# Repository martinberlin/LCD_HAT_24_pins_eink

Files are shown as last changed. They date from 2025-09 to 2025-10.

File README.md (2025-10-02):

LCD_HAT with 24 pin SPI Eink circuit<br>
-----------------------------------

Copyright (c) 2023 BitBank Software, Inc.<br>
bitbank@pobox.com<br>
<br>
Collaboration to make the SPI Eink port by [Fasani Corp](https://fasani.de)

A simple PCB to easily connect LCD breakout boards to Arduino Nano or Feather MCU boards. Includes 2 momentary push buttons and Qwiic I2C connector. The GPIOs used for the LCD connection are marked next to the female header. Likewise the buttons.
<br>
This photo shows an Arduino Nano RP2040 Connect and UnexpectedMaker FeatherS3 both using the same board and 2 types of LCDs supported with this pinout:
<br>
<br>
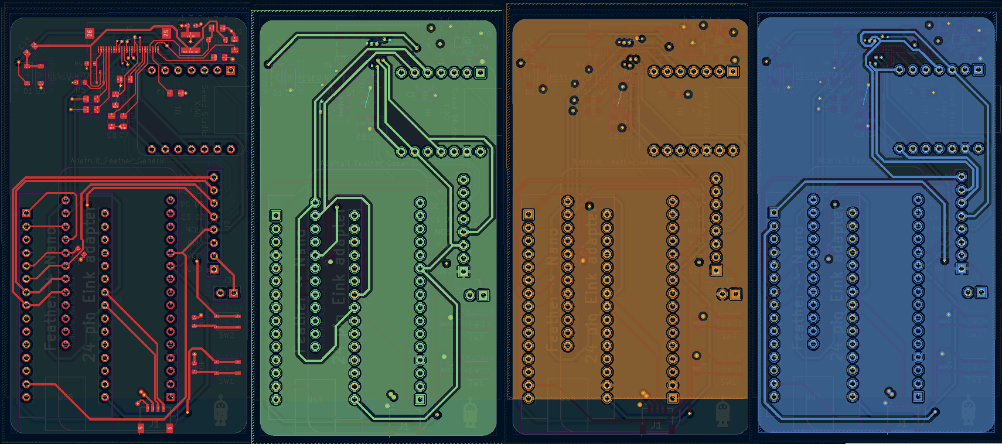
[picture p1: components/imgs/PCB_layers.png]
LCD_HAT layers

<br>
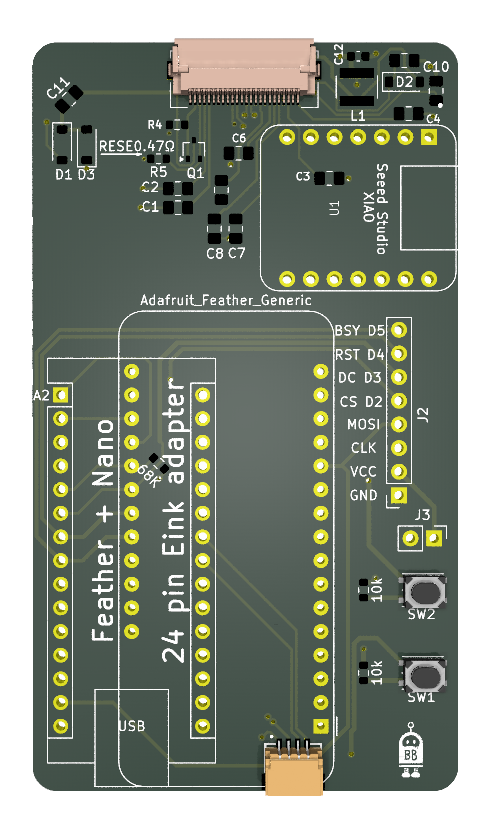
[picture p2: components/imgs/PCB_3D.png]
LCD_HAT 3D Render LCD_HAT 3D


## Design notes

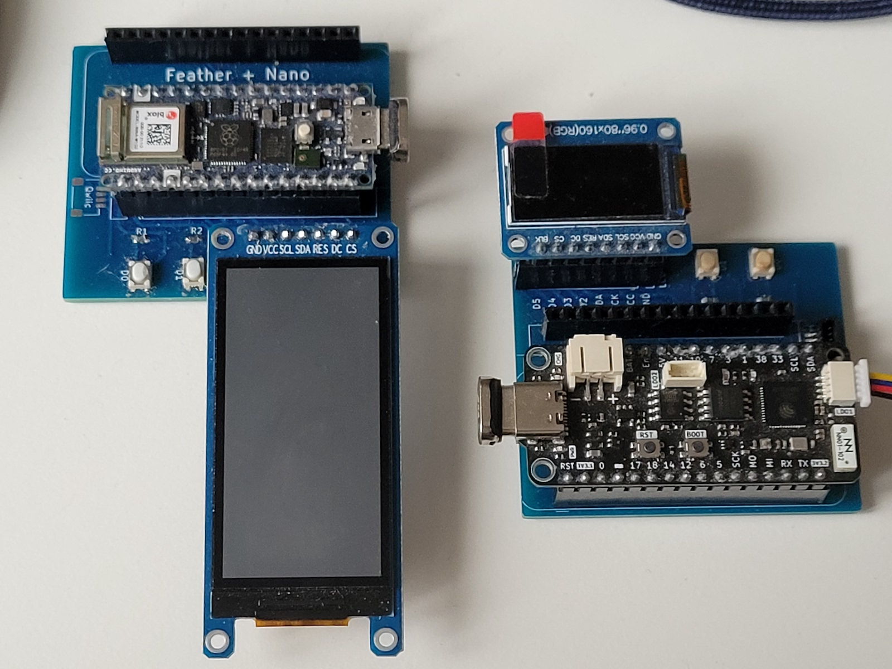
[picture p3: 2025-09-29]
demo.jpg

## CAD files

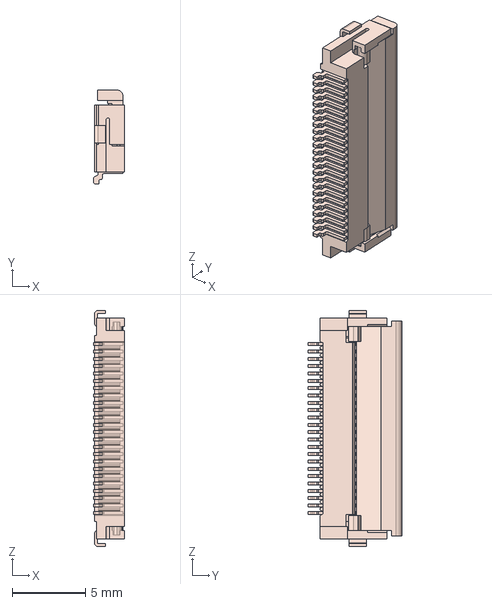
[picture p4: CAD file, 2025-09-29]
components/3d/FH12-24S-0.5SH_55_.step
2.10 x 6.40 x 16.1 mm

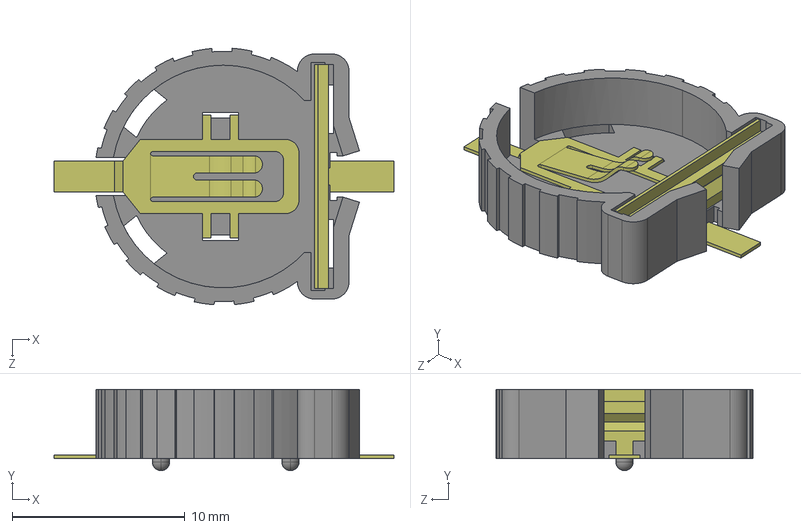
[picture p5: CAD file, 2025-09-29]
components/3d/CR1220-2.step
19.7 x 4.70 x 14.9 mm

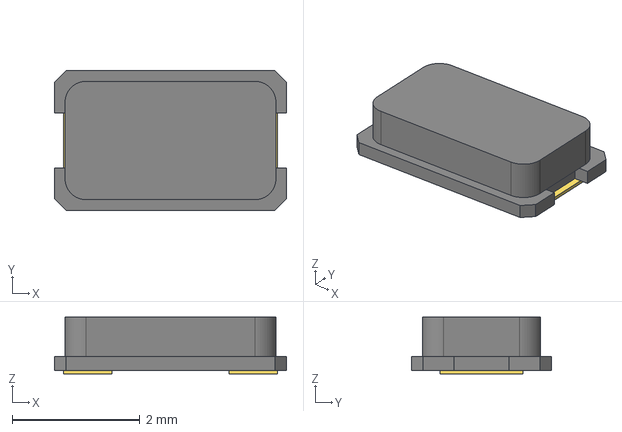
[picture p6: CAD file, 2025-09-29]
components/3d/XTAL_FC-135_EPS.step
3.63 x 2.18 x 0.889 mm

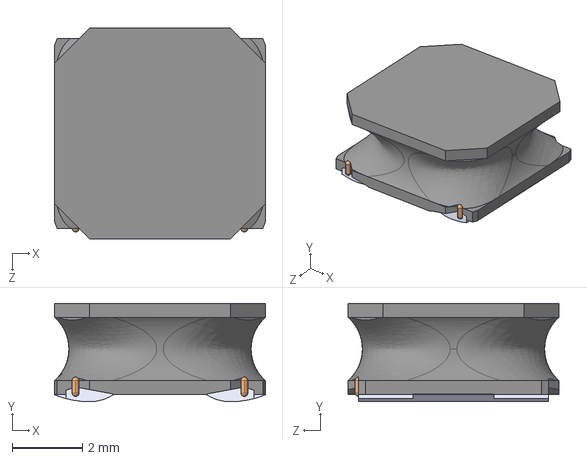
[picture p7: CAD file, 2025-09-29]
components/3d/L-40xx.STEP
6.00 x 2.80 x 6.00 mm

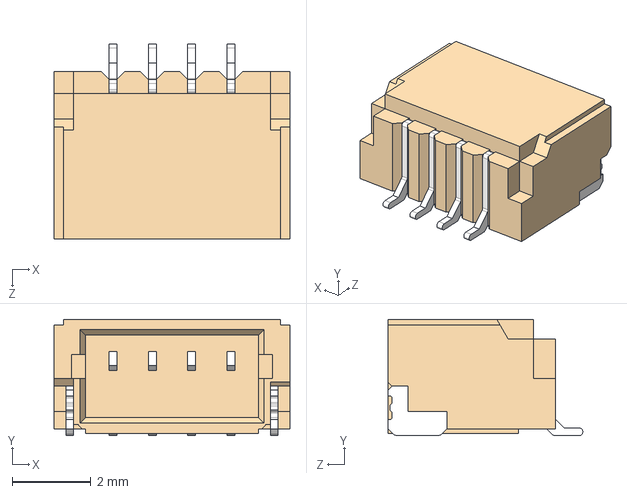
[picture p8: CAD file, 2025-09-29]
components/3d/QWIIC_SM04B-SRSS-TB_LF__SN_.stp
6.00 x 2.96 x 4.95 mm

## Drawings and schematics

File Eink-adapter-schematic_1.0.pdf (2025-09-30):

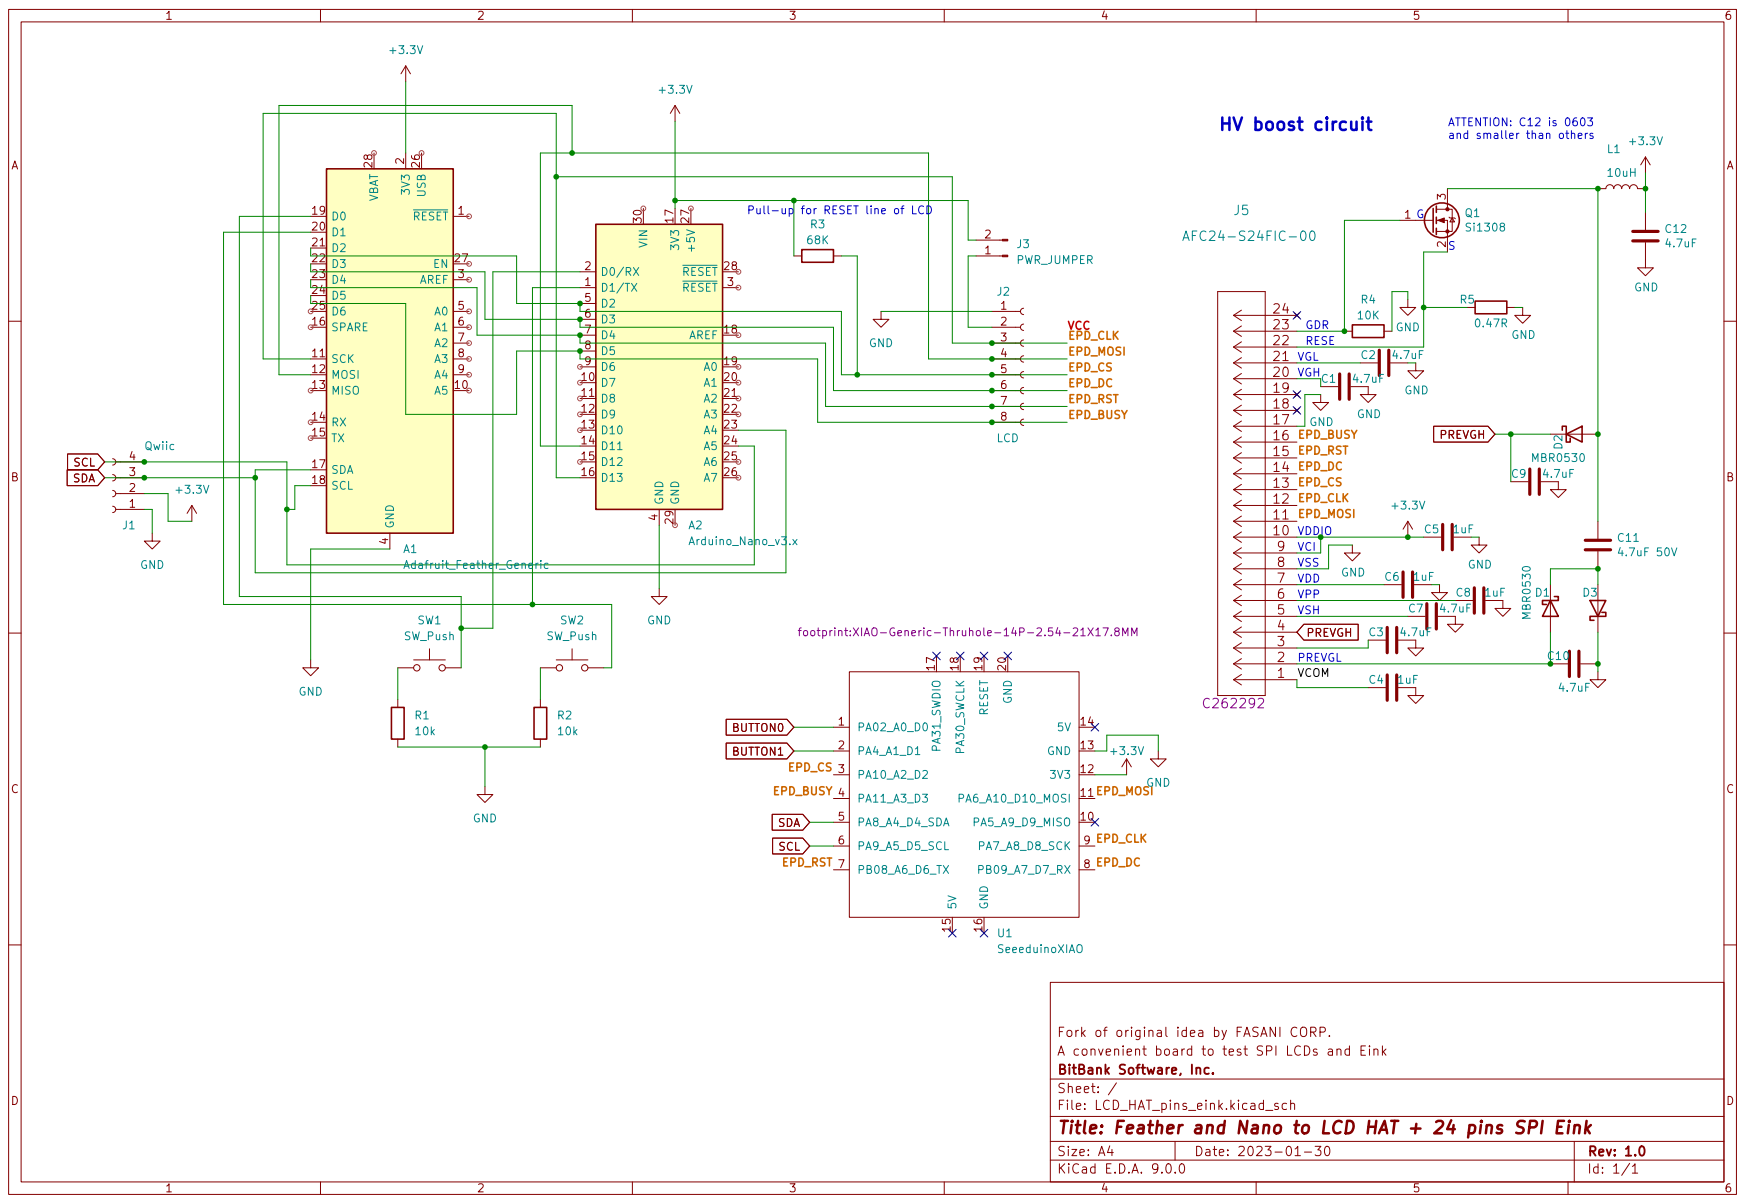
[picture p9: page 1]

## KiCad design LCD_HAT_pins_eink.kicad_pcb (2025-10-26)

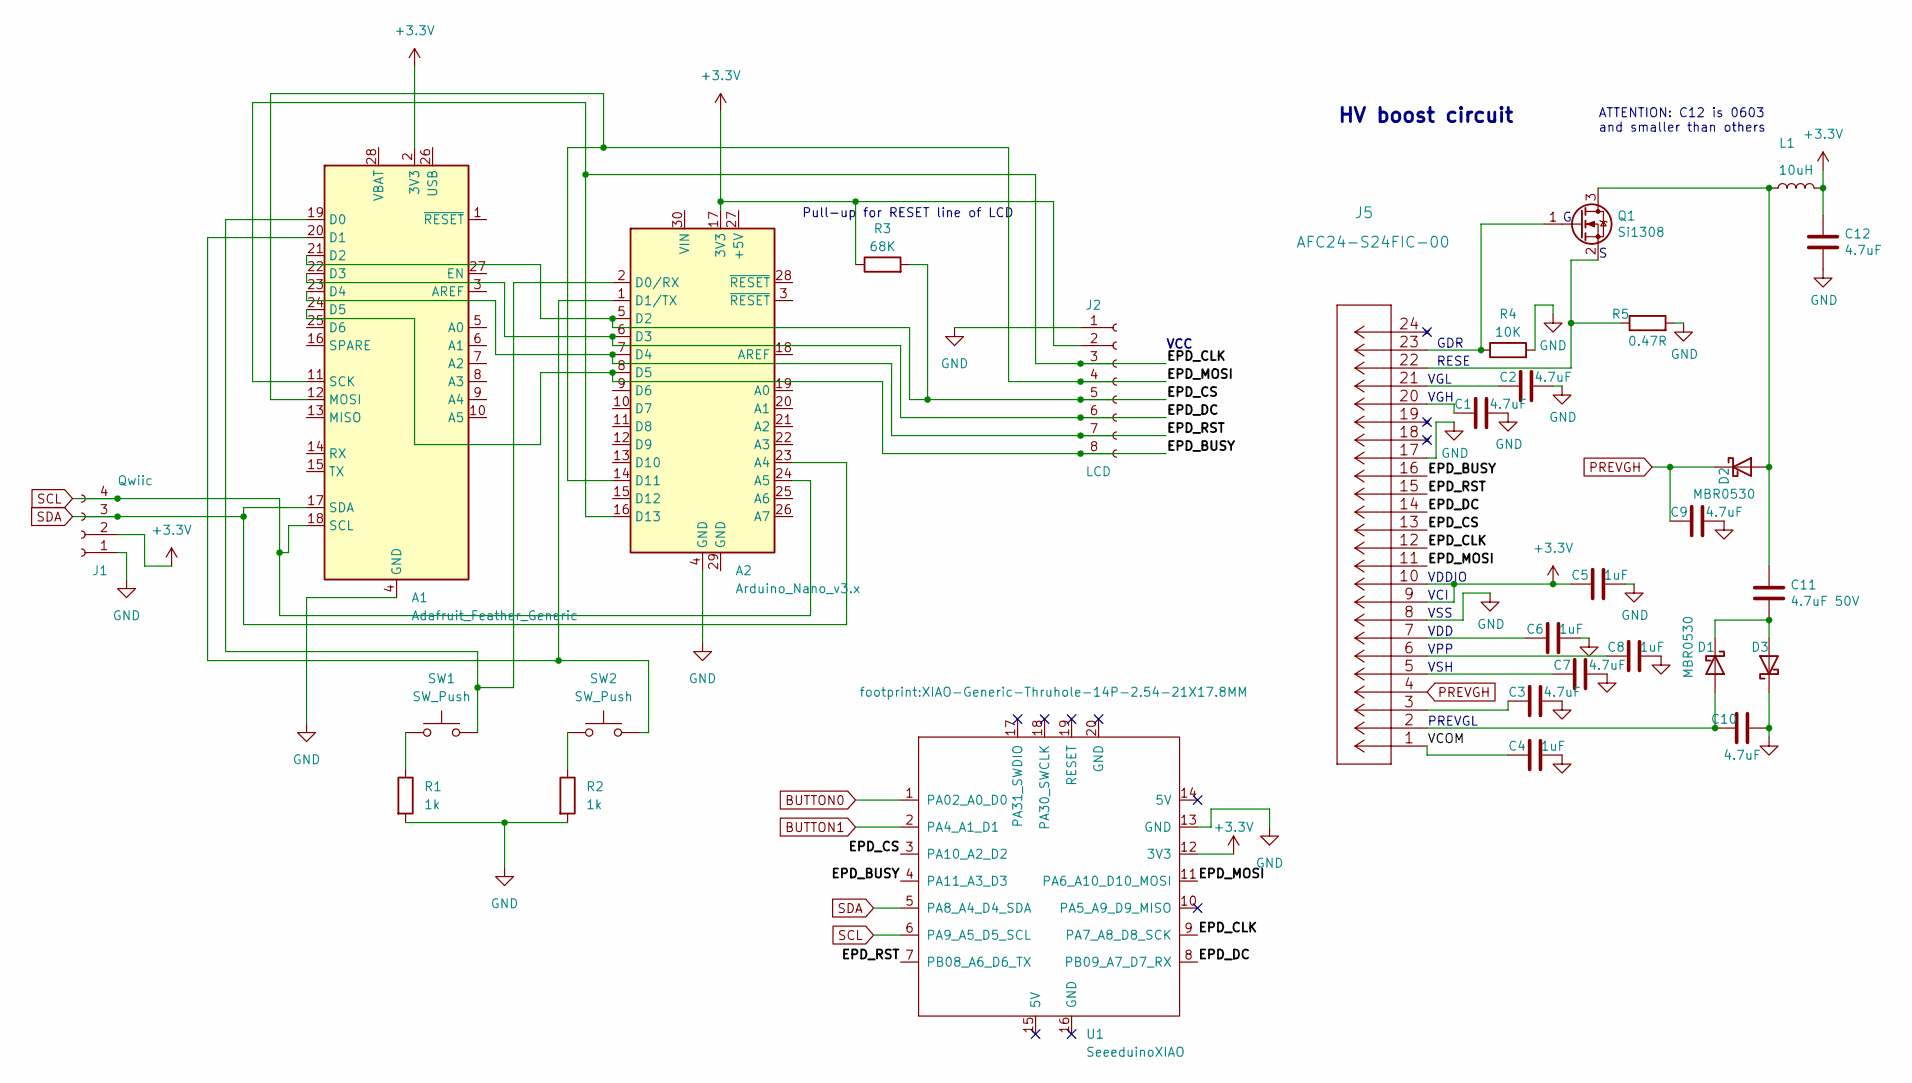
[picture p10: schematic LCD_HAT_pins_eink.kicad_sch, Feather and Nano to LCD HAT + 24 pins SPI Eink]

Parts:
A1: Adafruit_Feather_Generic; Adafruit_Feather
A2: Arduino_Nano_v3.x; Arduino_Nano
C1, C2, C3, C7, C9, C10: 4.7uF; C_0805_2012Metric_Pad1.18x1.45mm_HandSolder; LCSC C1779
C4, C5, C6, C8: 1uF; C_0805_2012Metric_Pad1.18x1.45mm_HandSolder; LCSC C28323
C11: 4.7uF 50V; C_0805_2012Metric_Pad1.18x1.45mm_HandSolder; LCSC C1779
C12: 4.7uF; C_0603_1608Metric; LCSC C19666
D1, D2, D3: MBR0530; D_SOD-123; LCSC C77336
J1: Qwiic; QWIIC_SM04B-SRSS-TB_LFSN_; LCSC C160404
J2: LCD; PinSocket_1x08_P2.54mm_Vertical
J5: AFC24-S24FIC-00; LCSC C262292
L1: 10uH; SWPA4030S1R0NT; LCSC C38117
Q1: Si1308; SOT-323_SC-70; LCSC C469327
R1, R2: 1k; R_0603_1608Metric; LCSC C11702
R3: 68K; R_0603_1608Metric; LCSC C245058
R4: 10K; R_0603_1608Metric; LCSC C25804
R5: 0.47R; R_0603_1608Metric; LCSC C103895
SW1, SW2: SW_Push; SW_Push_1P1T_NO_Vertical_Wuerth_434133025816; LCSC C19190908
U1: SeeeduinoXIAO; XIAO-Generic-Thruhole-14P-2.54-21X17.8MM

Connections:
+3.3V: A1.2 (3V3), A2.17 (3V3), C5.2, C12.2, J1.2, J2.2, J5.9, J5.10, L1.2, R3.1, U1.12 (3V3)
/EPD_BUSY: A1.24 (D5), A2.8 (D5), J2.8, J5.16, U1.4 (PA11_A3_D3)
/EPD_CLK: A1.11 (SCK), A2.16 (D13), J2.3, J5.12, U1.9 (PA7_A8_D8_SCK)
/EPD_CS: A1.21 (D2), A2.5 (D2), J2.5, J5.13, R3.2, U1.3 (PA10_A2_D2)
/EPD_DC: A1.22 (D3), A2.6 (D3), J2.6, J5.14, U1.8 (PB09_A7_D7_RX)
/EPD_MOSI: A1.12 (MOSI), A2.14 (D11), J2.4, J5.11, U1.11 (PA6_A10_D10_MOSI)
/EPD_RST: A1.23 (D4), A2.7 (D4), J2.7, J5.15, U1.7 (PB08_A6_D6_TX)
/VCOM: C4.2, J5.1
BUTTON0: U1.1 (PA02_A0_D0)
BUTTON1: U1.2 (PA4_A1_D1)
GND: A1.4 (GND), A2.4 (GND), C1.1, C2.1, C3.1, C4.1, C5.1, C6.1, C7.1, C8.1, C9.1, C10.1, C12.1, D3.1 (K), J1.1, J2.1, J5.8, J5.17, R1.2, R2.2, R4.2, R5.2, U1.13 (GND)
unnamed: A1.19 (D0), A2.2 (D0/RX), SW1.2
unnamed: A1.20 (D1), A2.1 (D1/TX), SW2.2
unnamed: C1.2, J5.20
unnamed: C2.2, J5.21
unnamed: C3.2, J5.3
unnamed: C6.2, J5.7
unnamed: C7.2, J5.5
unnamed: C8.2, J5.6
unnamed: C10.2, D1.2 (A), J5.2
unnamed: C11.1, D1.1 (K), D3.2 (A)
unnamed: C11.2, D2.2 (A), L1.1, Q1.3 (D)
unnamed: J5.23, Q1.1 (G), R4.1
unnamed: J5.22, Q1.2 (S), R5.1
unnamed: R1.1, SW1.1
unnamed: R2.1, SW2.1
PREVGH: C9.2, D2.1 (K), J5.4
SCL: A1.18 (SCL), A2.24 (A5), J1.4, U1.6 (PA9_A5_D5_SCL)
SDA: A1.17 (SDA), A2.23 (A4), J1.3, U1.5 (PA8_A4_D4_SDA)

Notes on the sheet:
PREVGL
VGH
ATTENTION: C12 is 0603 and smaller than others
VSS
VDD
RESE
VGL
Pull-up for RESET line of LCD
GDR
VCI
VCC
HV boost circuit
VDDIO
VPP
VSH

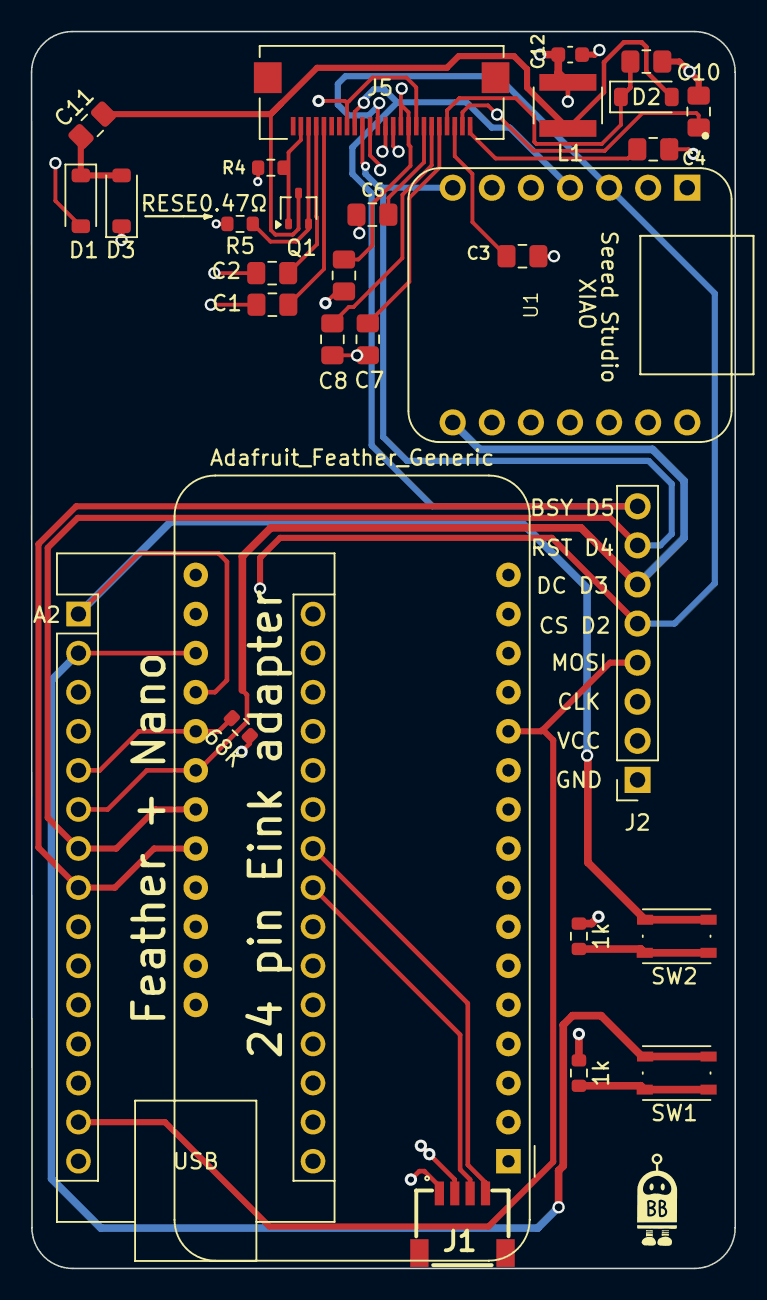
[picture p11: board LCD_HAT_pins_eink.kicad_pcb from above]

Board: 4 copper layers, 45.7 x 80.4 mm, 30 parts (0 on the bottom side), 27 nets.

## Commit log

2025-09-30 Rework routing
    [LCD_HAT_pins_eink.kicad_pcb, LCD_HAT_pins_eink.kicad_sch]
2025-10-02 Update readme with images
    [LCD_HAT_pins_eink.kicad_pcb]
2025-10-03 FAB Files 1.0
    [LCD_HAT_pins_eink.kicad_pcb, LCD_HAT_pins_eink.kicad_sch]
2025-10-26 FIX pin not connected to GND in 24 pin FPC
    [LCD_HAT_pins_eink.kicad_pcb, LCD_HAT_pins_eink.kicad_sch]

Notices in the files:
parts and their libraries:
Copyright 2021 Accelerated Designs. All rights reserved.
